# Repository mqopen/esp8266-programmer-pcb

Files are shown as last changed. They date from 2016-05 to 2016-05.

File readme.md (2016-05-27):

# ESP8266 programmer

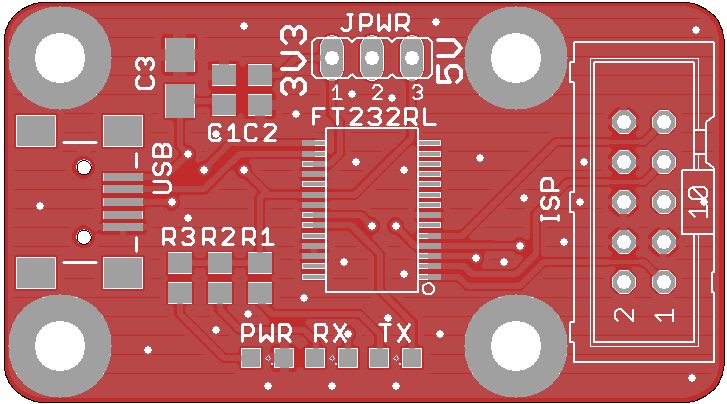
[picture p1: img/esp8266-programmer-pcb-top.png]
ESP8266 pprogrammer


This is part of [mqopen](http://mqopen.org) project.

## Features

 - Board dimensions: 1800 x 1000 mils (45.72 x 25.4 mm).
 - FT232RL chip.
 - Connected using mini USB socket (4 legs SMD).
 - PWR, RX and TX LEDs.
 - 10 pin AVR like header for programming ribbon cable.

## Get board

You can order PCB on this [link](http://dirtypcbs.com/view.php?share=20024&accesskey=b40cd2f50915caacdd38e3f2a6016732).

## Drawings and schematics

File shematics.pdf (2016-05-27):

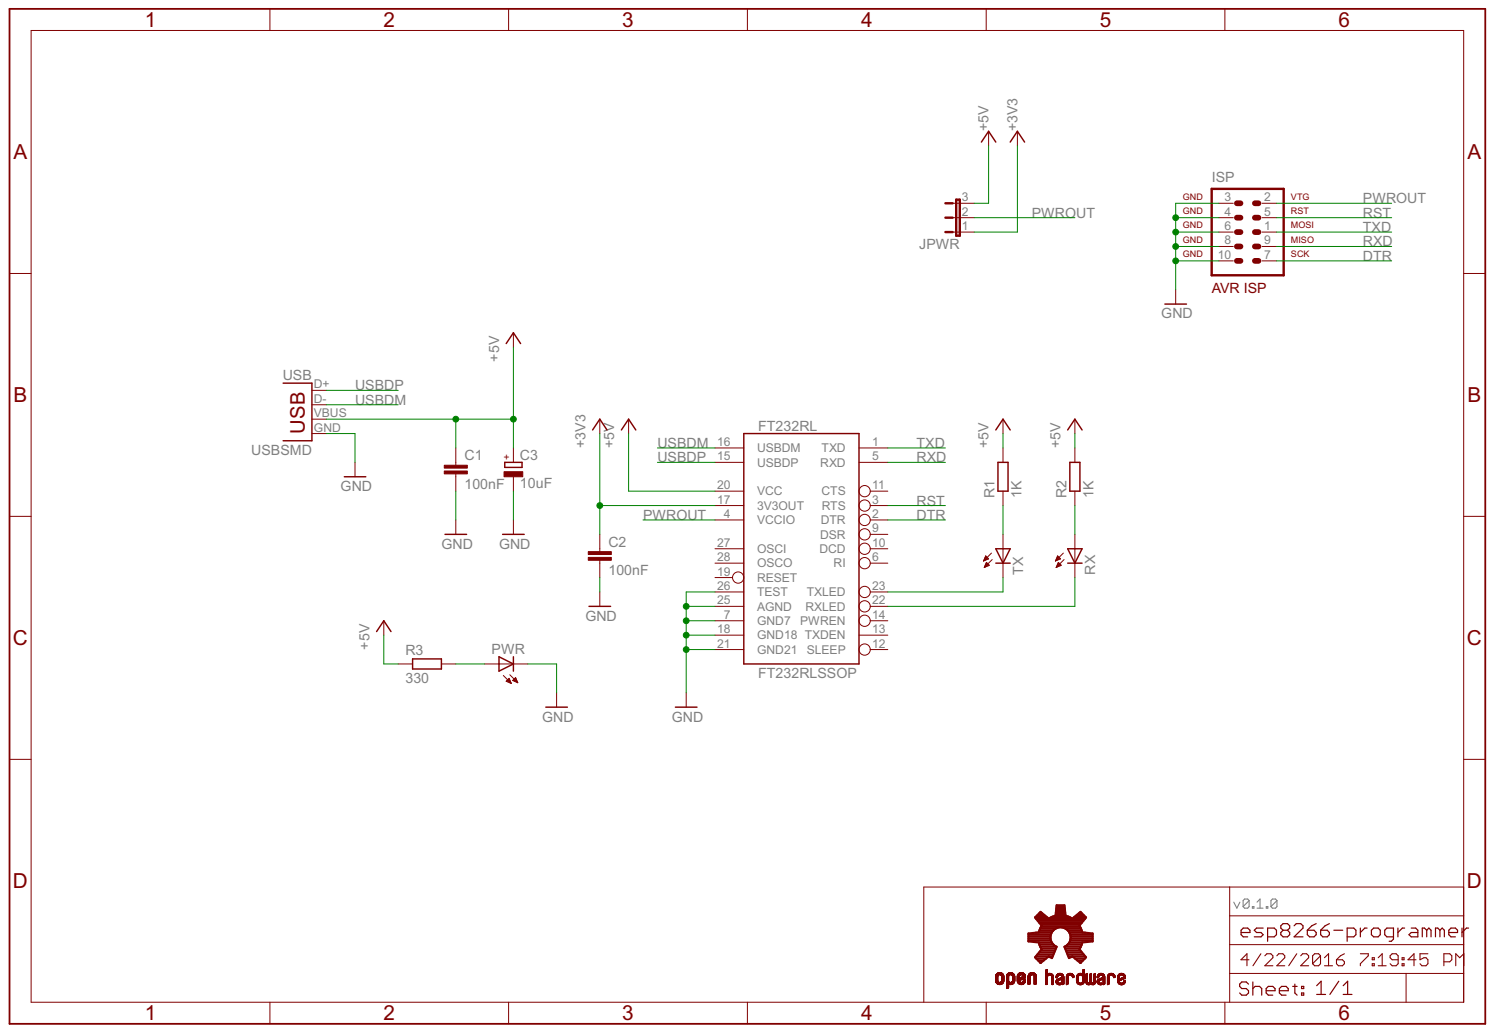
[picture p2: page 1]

ISP
GND GND

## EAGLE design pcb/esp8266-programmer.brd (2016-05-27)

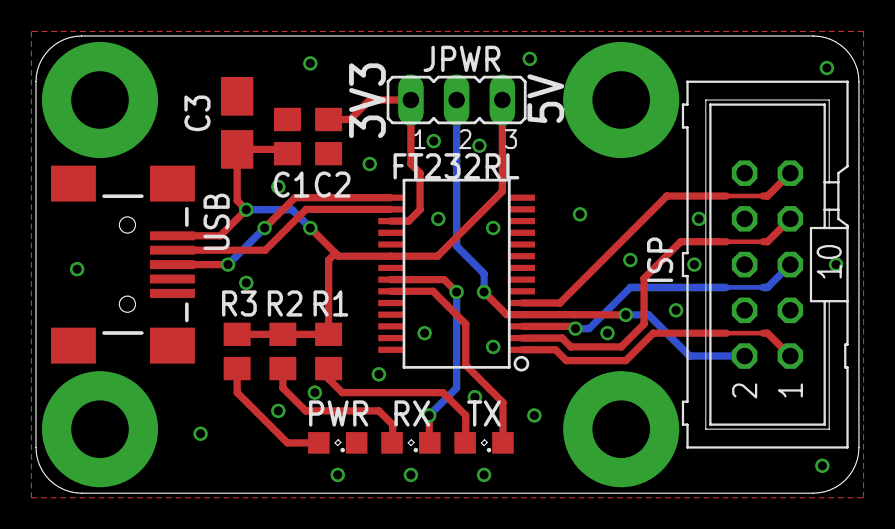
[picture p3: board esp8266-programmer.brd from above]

Board: 2 copper layers, 45.7 x 25.4 mm, 14 parts (1 on the bottom side), 15 nets.

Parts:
C1, C2: 100nF; C0805
C3: 10uF; A/3216-18W
FT232RL: FT232RLSSOP; SSOP28DB
ISP: AVR-ISP-10ML; ML10
JPWR: JP2
LOGO1: OSHW-LOGOL; OSHW-LOGO-L
PWR: SML0805
R1, R2: 1K; R0805
R3: 330; R0805
RX: SML0805
TX: SML0805
USB: USBSMD; USB-MINIB

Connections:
+3V3: C2.1, FT232RL.17, JPWR.1
+5V: C1.1, C3.+, FT232RL.20, JPWR.3, R1.2, R2.2, R3.1, USB.VBUS
DTR: FT232RL.2, ISP.7
GND: C1.2, C2.2, C3.-, FT232RL.7, FT232RL.18, FT232RL.21, FT232RL.25, FT232RL.26, ISP.3, ISP.4, ISP.6, ISP.8, ISP.10, PWR.C, USB.GND
unnamed: PWR.A, R3.2
unnamed: R1.1, TX.A
unnamed: R2.1, RX.A
PWROUT: FT232RL.4, ISP.2, JPWR.2
RST: FT232RL.3, ISP.5
RX: FT232RL.22, RX.C
RXD: FT232RL.5, ISP.9
TX: FT232RL.23, TX.C
TXD: FT232RL.1, ISP.1
USBDM: FT232RL.16, USB.D-
USBDP: FT232RL.15, USB.D+

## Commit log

2016-04-22 Initial board design.
    [esp8266-programmer.brd, esp8266-programmer.sch]
2016-05-27 Final board design.
    [esp8266-programmer.brd, esp8266-programmer.sch]
2016-05-27 Added schematics file.

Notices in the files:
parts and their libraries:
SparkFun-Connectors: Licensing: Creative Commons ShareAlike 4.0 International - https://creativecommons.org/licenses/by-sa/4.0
